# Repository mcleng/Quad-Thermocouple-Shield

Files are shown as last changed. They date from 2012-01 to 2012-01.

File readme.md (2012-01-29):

Quad Thermocouple Shield
==========================

This work is licensed under a <a rel="license" href="http://creativecommons.org/licenses/by-sa/3.0/">Creative Commons Attribution-ShareAlike 3.0 Unported License</a>.


	
Designed By:

*	Ryan McLaughlin <ryan@ryanjmclaughlin.com>

Summary
-------

The thermocouple shield was based upon the original breakout board developed for the MAX6675.  While this is a great little chip it is a small surface mount part and therefore difficult to solder. The thermocouple shield helps with having the MAX31855 chip broken out to a simple 0.1" header, a direct interface the the shield, and also provides a PCB Thermocouple Connector to easily interface to a thermocouple. Thermocouple wires are not designed to be soldered and this provides a good solid connection, while also using the proper metals in the connector required for a thermocouple connection.

Connections to Arduino pins are through solder jumpers (normally-closed), however trace is easily cuttable to be able to re-map connections to different pins.  The TXB0106 level shifter to translates 5V Arduino signals to the MAX31855 (3.3V) so the shield can be used with 5V and 3.3V Arduino platforms. Arduino reset switch on the shield.  A secondary set of headers to breakout Arduino pins along sides of the shield to allow for easy prototyping or re-mapping of connections.

Board Specs
-----------

*	Dimensions: Arduino Shield
*	Chip: MAX31855 (4), TXB0106 (1)
*	Voltage: 5V, 3.3V
*	Header: 2 - 1x6 0.1" Pitch, 2 - 1x8 0.1" Pitch
*	Alternate Connection: 2x5 0.1" Pitch header
*	Fixturing: Matching holes to Arduino
*	Pin Connections
	*	13 - SCK
	*	12 - SO
	*	10 - CS1
	*	9 - CS2
	*	8 - CS3
	*	7 - CS4
	*	6 - LED1

Tutorial
--------

It is simple to get everything up and running.

1.	Install a set of shield headers or shield stacking headers to the board
2.	(Optional) Cut solder jumpers if you need to connect the MAX31855 to different pins but adding jumpers between center header and shield pins.
3.	Connect a K-Type [Thermocouple](http://en.wikipedia.org/wiki/Thermocouple Thermocouple)
4.	Load one of the samples from the [[MAX31855 Arduino Library]] and you should see temperature information in the serial console.

Versions
--------

###v2.0

This version changed to the MAX31855 thermocouple chip. Other changes included:

* Initial release under Eagle 6.1 on Github
* Change to MAX31855 chip
* Change solder jumpers to be normally-closed, however trace is easily cuttable
* Added TXB0106 level shifter to translate 5V Arduino signals to the MAX31855
* Updated board dimensions to Adafruit Eagle Library definition
* Updated fixturing holes to follow Arduino fixturing holes
* Added Arduino reset switch
* Added secondary set of headers to breakout Arduino pins along sides of the shield
* Updated prototyping holes to fall on same 0.1" grid as Arduino headers
* PCB production dates 09-2011

####Board Specs
* Dimensions: Arduino Shield
* Chip: MAX31855 (4), TXB0106
* Voltage: 5V, 3.3V
* Header: 2 - 1x6 0.1" Pitch, 2 - 1x8 0.1" Pitch
* Fixturing: Matching holes to Arduino

###Version 1.3

This version made some minor changes based on some feedback of the original version.  The changes included:

* Addition of solder jumpers to allow for disconnection of shield header traces
* The solder mask was not updated on this board and still shows V1.2, however the board is V1.3

####Board Specs
* Dimensions: Arduino Shield
* Chip: 1, 2, or 4 MAX6675
* Header: 2 - 1x6 0.1" Pitch, 2 - 1x8 0.1" Pitch
* Fixturing: Three Corner Holes

###Version 1.2

This board is adapted from the Quad Thermocouple Interface and made to be in a shield format.  It is designed to be able to use 1-4 MAX6675 chips to interface to thermocouples.  One end of the board is left open with 0.1" pitch holes for prototyping space.  Unfortunately due the the height of the thermocouple connectors the shields must be the top shield.

####Board Specs
* Dimensions: Arduino Shield
* Chip: 1, 2, or 4 MAX6675
* Header: 2 - 1x6 0.1" Pitch, 2 - 1x8 0.1" Pitch
* Fixturing: Three Corner Holes

Software
--------

See [[MAX31855 Arduino Library]] for code examples.

Purchase
--------

[store.ryanjmclaughlin.com](http://store.ryanjmclaughlin.com) 

TODO
----

*	Do not route LED through level shifter
*	Add 3.3V connection to center 2x5 header
*	Move reset button further from tc connector

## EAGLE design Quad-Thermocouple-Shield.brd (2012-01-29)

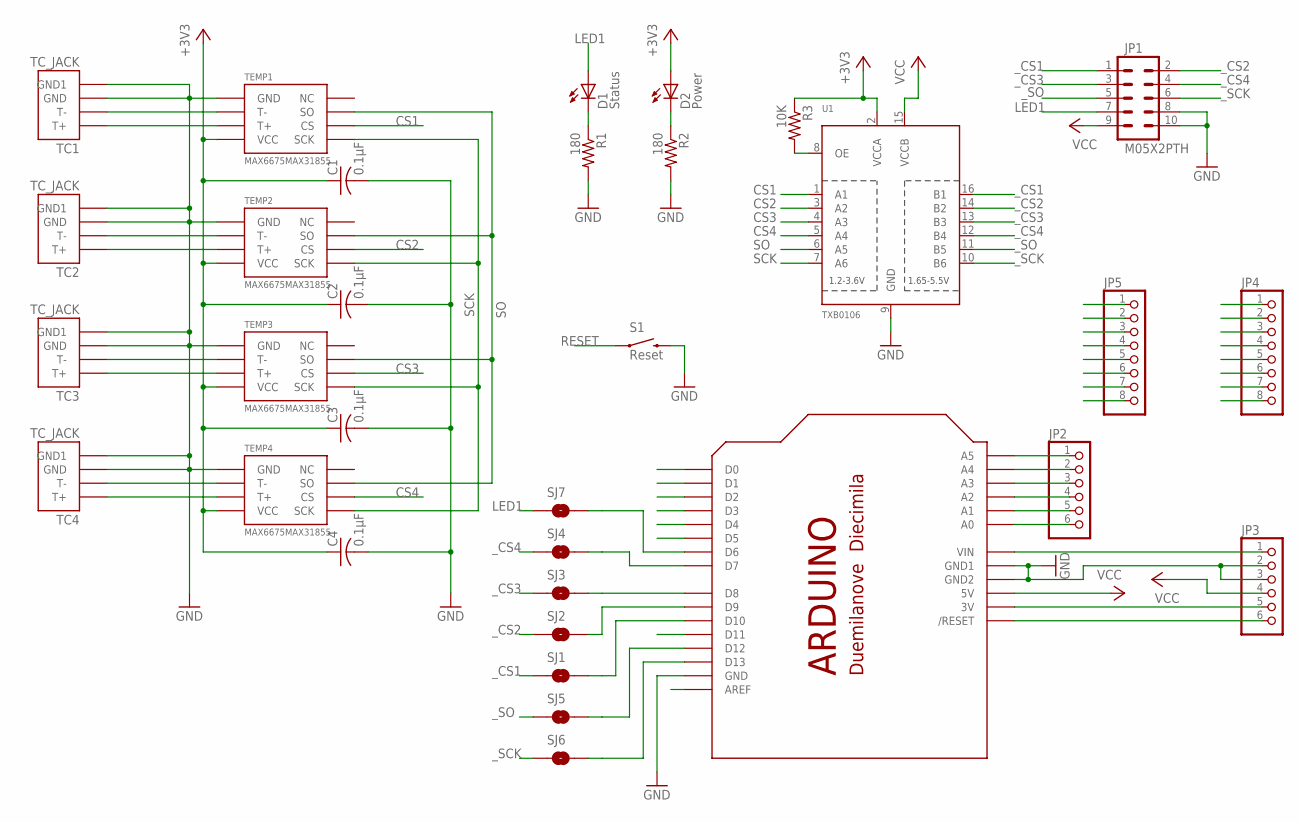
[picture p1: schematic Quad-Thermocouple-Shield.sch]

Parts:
C1, C2, C3, C4: 0.1µF; C0603
D1: Status; CHIPLED_0805
D2: Power; CHIPLED_0805
JP1: M05X2PTH; AVR_ICSP
JP2, JP3: PINHD-1X6CB; 1X06-CLEANBIG
JP4, JP5: PINHD-1X8CLEANBIG; 1X08-CLEANBIG
R1, R2: 180; R0603
R3: 10K; R0603
S1: Reset; TACTILE_SWITCH_SMD
SJ1, SJ2, SJ3, SJ4, SJ5, SJ6, SJ7: SOLDERJUMPERTRACE; SJ_2S-TRACE
TC1, TC2, TC3, TC4: TC_JACK
TEMP1, TEMP2, TEMP3, TEMP4: MAX6675MAX31855; SOIC-8
U1: TXB0106; TSSOP16
U$3: ARDUINOUNO; ARDUINO

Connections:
+3V3: C1.1, C2.1, C3.1, C4.1, D2.A, JP3.5, R3.1, TEMP1.VCC, TEMP2.VCC, TEMP3.VCC, TEMP4.VCC, U1.2 (VCCA), U$3.3V
AREF: JP4.8, U$3.AREF
CS1: TEMP1.CS, U1.1 (A1)
CS2: TEMP2.CS, U1.3 (A2)
CS3: TEMP3.CS, U1.4 (A3)
CS4: TEMP4.CS, U1.5 (A4)
D0: JP5.1, U$3.D0
D1: JP5.2, U$3.D1
D2: JP5.3, U$3.D2
D3: JP5.4, U$3.D3
D4: JP5.5, U$3.D4
D5: JP5.6, U$3.D5
D6: JP5.7, SJ7.2, U$3.D6
D7: JP5.8, SJ4.2, U$3.D7
D8: JP4.1, SJ3.2, U$3.D8
D9: JP4.2, SJ2.2, U$3.D9
D10: JP4.3, SJ1.2, U$3.D10
D11: JP4.4, U$3.D11
D12: JP4.5, SJ5.2, U$3.D12
D13: JP4.6, SJ6.2, U$3.D13
GND: C1.2, C2.2, C3.2, C4.2, JP1.8, JP1.10, JP3.2, JP3.3, JP4.7, R1.2, R2.2, S1.3 (2), TC1.P$1 (GND), TC1.P$2 (GND1), TC2.P$1 (GND), TC2.P$2 (GND1), TC3.P$1 (GND), TC3.P$2 (GND1), TC4.P$1 (GND), TC4.P$2 (GND1), TEMP1.GND, TEMP2.GND, TEMP3.GND, TEMP4.GND, U1.9 (GND), U$3.GND, U$3.GND1, U$3.GND2
LED1: D1.A, JP1.7, SJ7.1
unnamed: D1.C, R1.1
unnamed: JP2.1, U$3.A5
unnamed: JP2.2, U$3.A4
unnamed: D2.C, R2.1
unnamed: JP2.3, U$3.A3
unnamed: JP2.4, U$3.A2
unnamed: R3.2, U1.8 (OE)
unnamed: JP2.5, U$3.A1
unnamed: JP2.6, U$3.A0
unnamed: JP3.1, U$3.VIN
RESET: JP3.6, S1.1, U$3.RESET (/RESET)
SCK: TEMP1.SCK, TEMP2.SCK, TEMP3.SCK, TEMP4.SCK, U1.7 (A6)
SO: TEMP1.SO, TEMP2.SO, TEMP3.SO, TEMP4.SO, U1.6 (A5)
T1+: TC1.T+, TEMP1.T+
T1-: TC1.T-, TEMP1.T-
T2+: TC2.T+, TEMP2.T+
T2-: TC2.T-, TEMP2.T-
T3+: TC3.T+, TEMP3.T+
T3-: TC3.T-, TEMP3.T-
T4+: TC4.T+, TEMP4.T+
T4-: TC4.T-, TEMP4.T-
VCC: JP1.9, JP3.4, U1.15 (VCCB), U$3.5V
_CS1: JP1.1, SJ1.1, U1.16 (B1)
_CS2: JP1.2, SJ2.1, U1.14 (B2)
_CS3: JP1.3, SJ3.1, U1.13 (B3)
_CS4: JP1.4, SJ4.1, U1.12 (B4)
_SCK: JP1.6, SJ6.1, U1.10 (B6)
_SO: JP1.5, SJ5.1, U1.11 (B5)

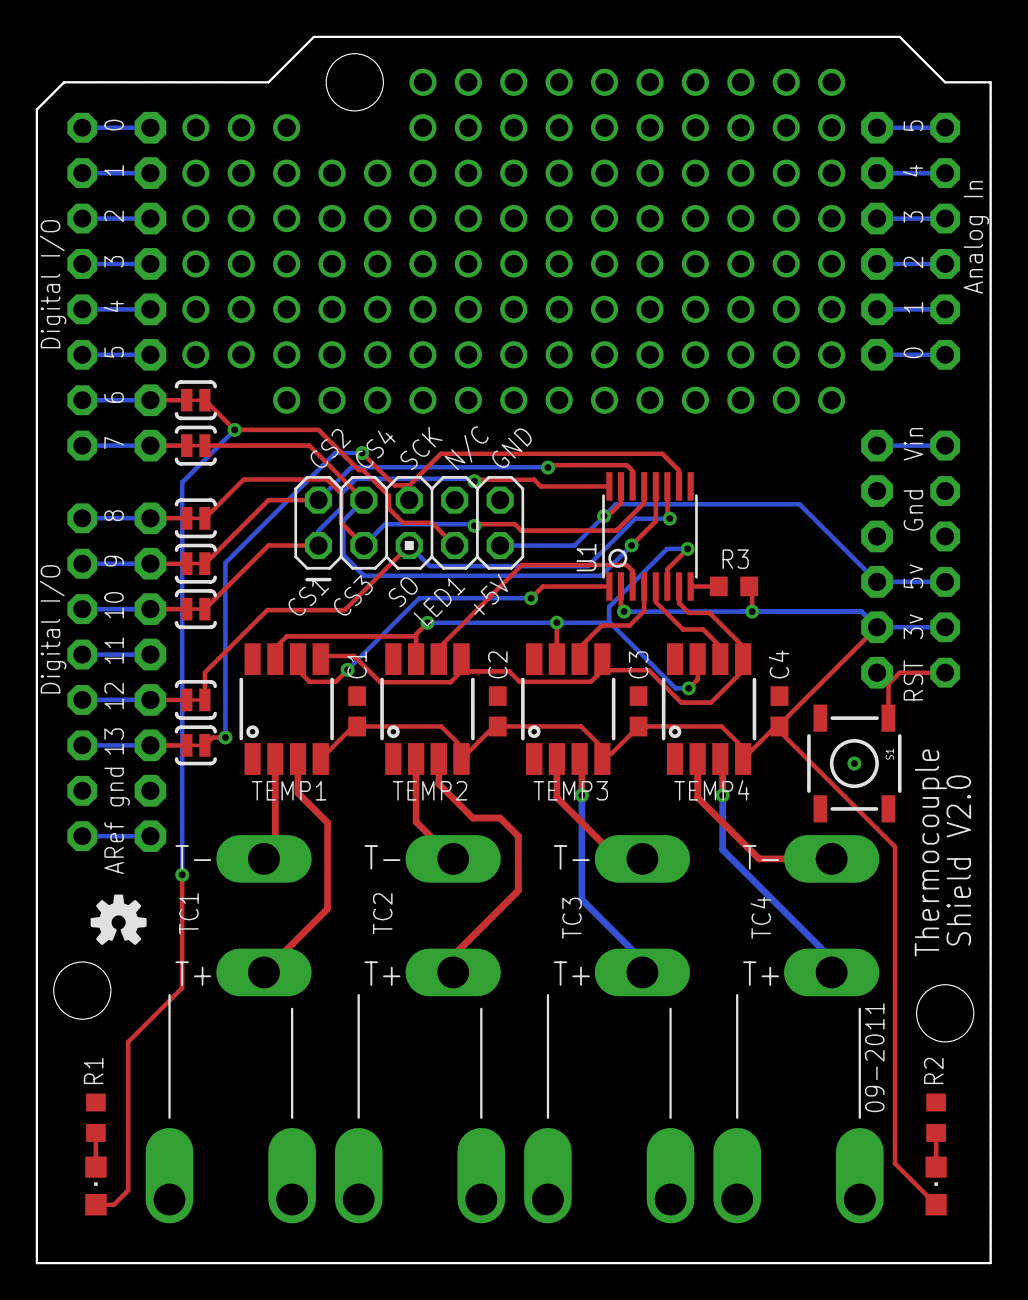
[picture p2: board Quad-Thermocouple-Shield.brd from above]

Board: 2 copper layers, 53.3 x 68.6 mm, 33 parts (0 on the bottom side), 50 nets.

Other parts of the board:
U$2: OSHW-LOGO-S

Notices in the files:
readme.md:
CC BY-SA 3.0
